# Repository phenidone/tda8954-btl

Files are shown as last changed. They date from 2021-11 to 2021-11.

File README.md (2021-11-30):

# TDA8954 Bridge Tied Load

This is a PCB design for a mono amplifier, using a TDA8954J in BTL configuration.

## Power

The board requires 41+41V DC.  Filtering caps are included, but a bridge 
rectifier is not as this is expected to be used with a switching supply.

The datasheet claims 420W into 8 ohms at 10% THD, or 330W at 0.5%, with a
41+41V supply.

The load impedance shall not be less than 8 ohms nominal.

## Unmute

The muting circuits are controlled via an opto-isolated input.  Provide 
5-24VDC on the UNMUTE port to enable the amplifiers.  This port allows the
amplifier to be put into a standby/mute mode, e.g. while preamplifiers are
booting.

## Components

Input capacitors (C7, C10) shall be film-type box capacitors, 5mm lead pitch.

The capacitor voltage ratings required are as follows:
 * Single-rail electrolytics (470uF) should be 63V
 * Dual-rail electrolytics (22uF) should be 160V
 * Single-rail MLCC (mostly 100n) should be 100V
 * Dual-rail MLCC supply caps should be 250V
 * Bootstrap and snubber MLCCs should be 250V
 * Output LC filter caps (C5, C11) are to be high-voltage (400V) film type

The output LC inductors should be low-loss cores with a saturation current
of not less than 10A.  Footprints are provided for
both Bourns SRP1265C (SMD shielded) and 2200HT-V (toroidal), though 
the toroids will overhang the edge of the PCB.  If toroidal inductors are used,
they should be affixed to the PCB with epoxy to prevent lead fatigue from 
vibration.

Power and output connectors are FASTON 1/4" spade terminals, though an extra
footprint for a 3-way screw terminal is provided for power input.

## EMI

The heatsink should be electrically connected to the HEATSINK spade terminal
connector at the corner of the board, and/or connected to safety-ground.

## License

This hardware design is (C) 2021 William Brodie-Tyrrell and is licensed under 
the CERN OHL; see cern_ohl_v_1_2.pdf

## TRL

This PCB has been sent for manufacture but not yet assembled or tested.

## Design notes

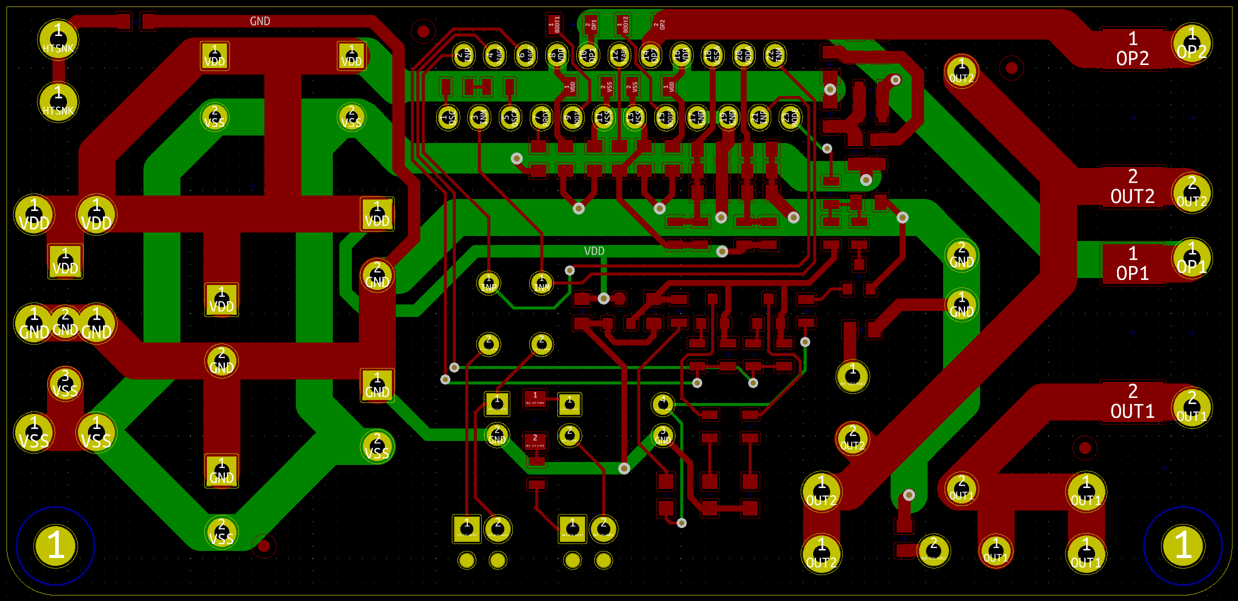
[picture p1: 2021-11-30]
tda8954-btl-layout.png

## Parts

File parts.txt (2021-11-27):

470u 63v electro, 4 of, multicomp MCRH63V477M13X26
22u 160v electro, 2 of, nichicon UVZ2C220MPD1TD
100n 250v 1206, 2 of, Wurth 885342208004
100n 100v 0805, 10 of, Multicomp MC0805B104K101CT
15n 250v 1206, 2 of, Kemet C1206C153KARECAUTO
220p 250v 0805, 4 of, Yageo CC0805KRX7RYBB221

1u film 5mm, 2 of, Wima MKS2C041001F00KSSD
22uH, 2 of, bourns SRP1265C-220M alt 2200HT-220-V-RC
680n film 15mm, 2 of, multicomp MPMPP400P68J0I200

terminal 2 way 3041529 15A
terminal 3 way 3041530 15A

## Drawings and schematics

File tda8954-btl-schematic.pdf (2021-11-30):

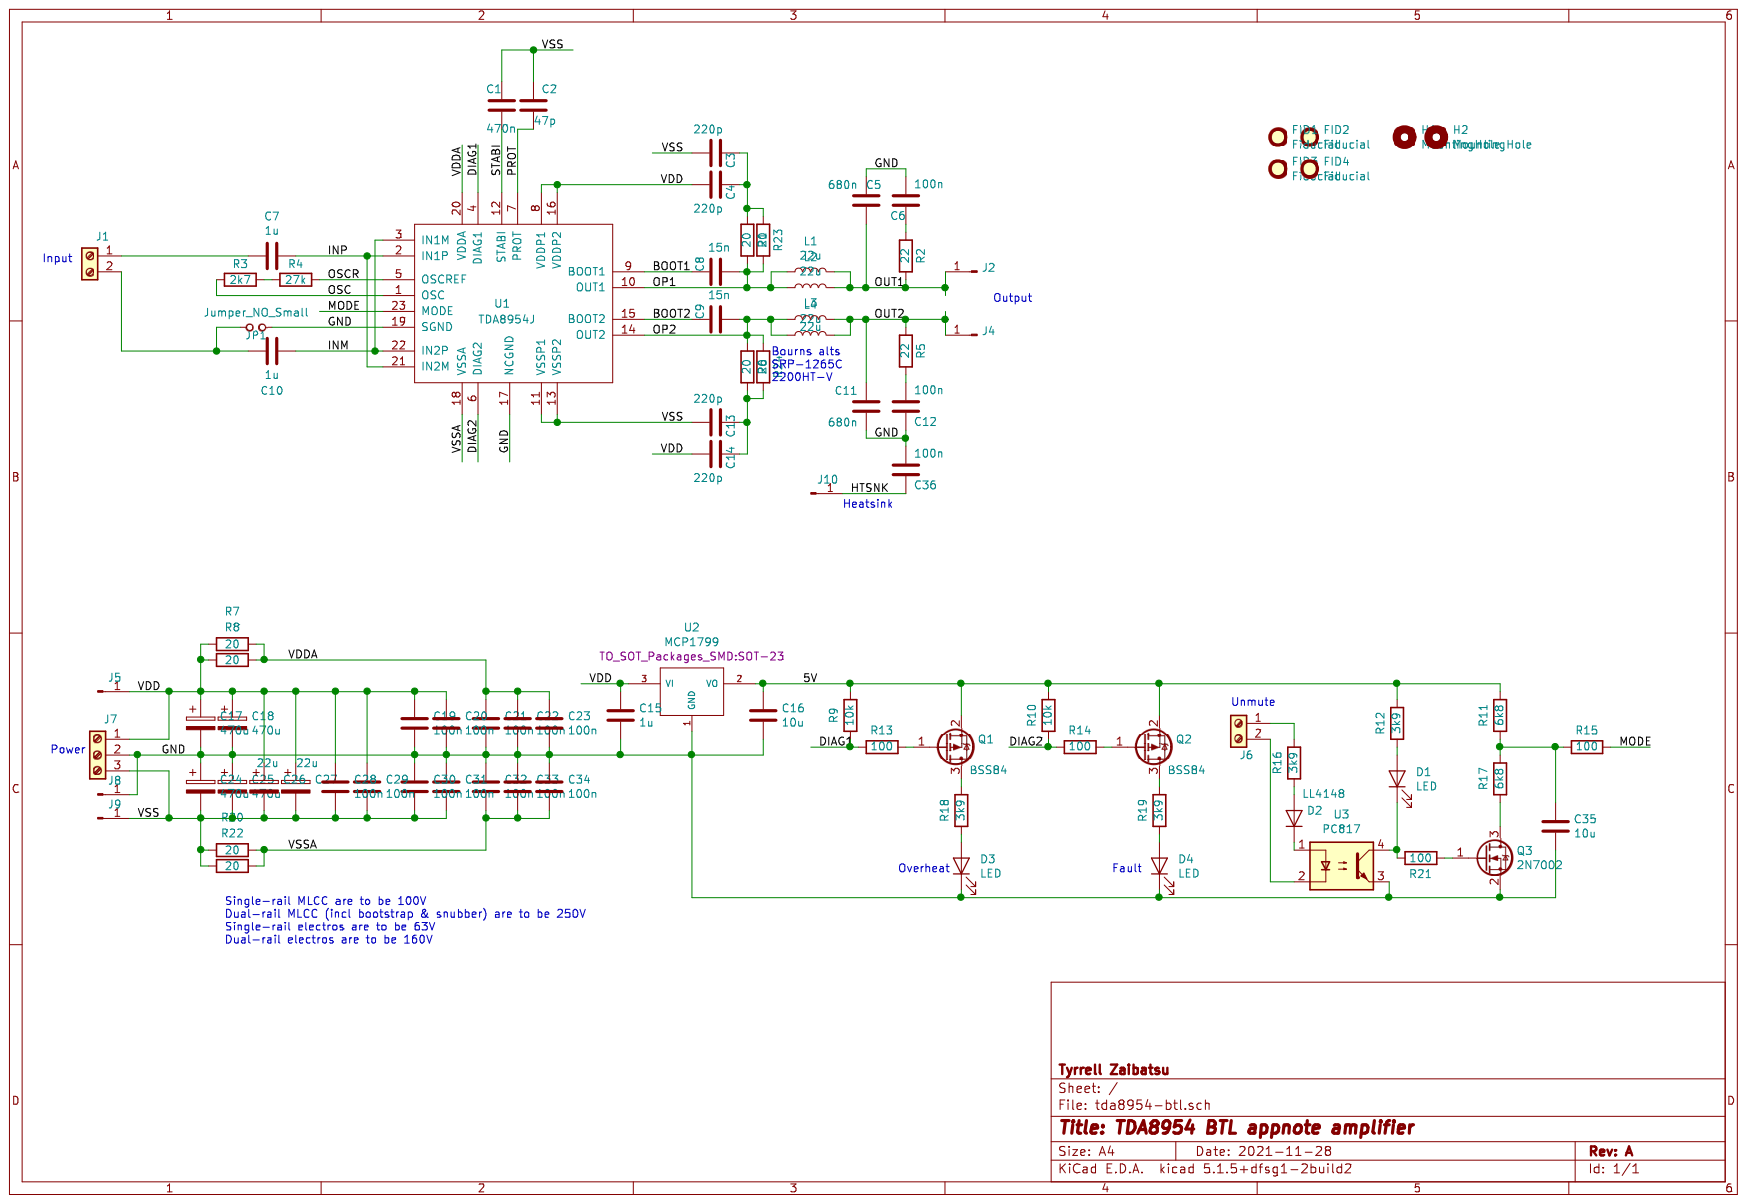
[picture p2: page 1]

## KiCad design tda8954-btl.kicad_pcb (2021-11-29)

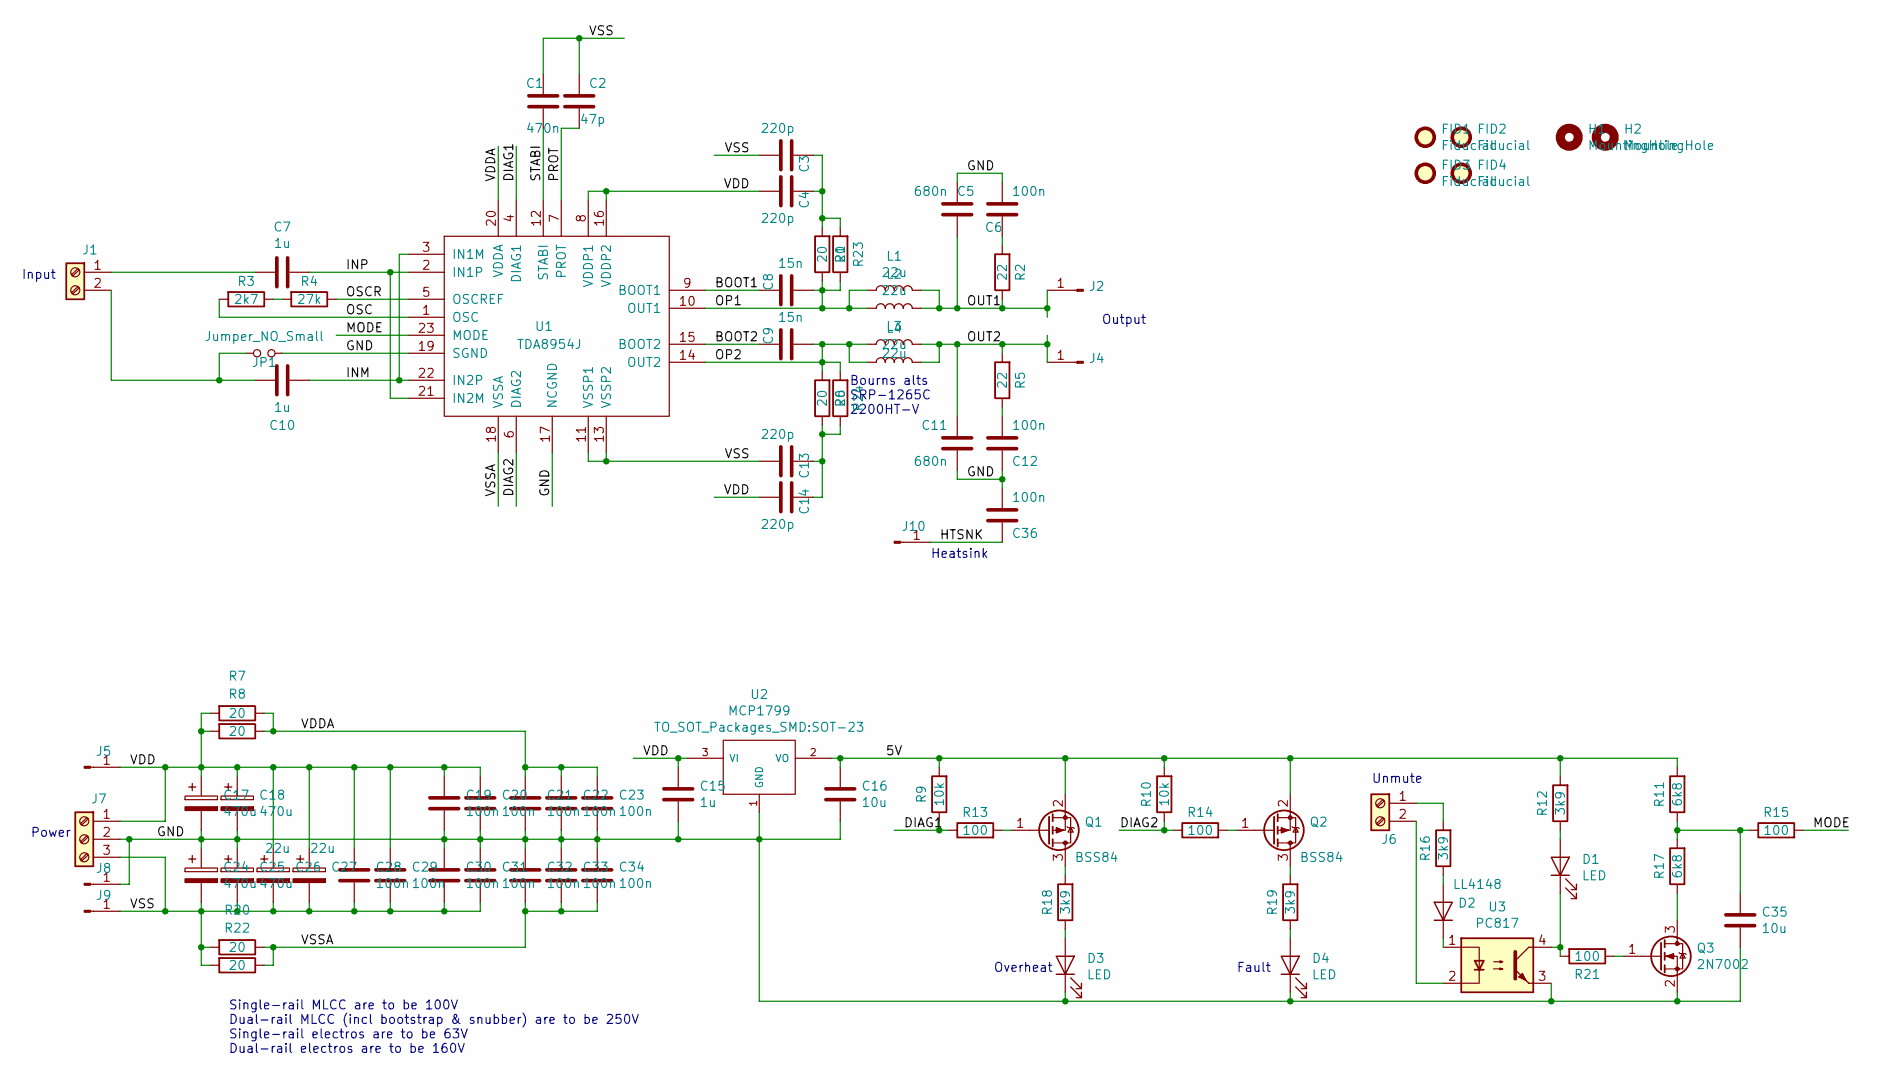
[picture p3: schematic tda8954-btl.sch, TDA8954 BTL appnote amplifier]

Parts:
C1: 470n; C_0805
C2: 47p; C_0805
C3, C4, C13, C14: 220p; C_0805
C5, C11: 680n; C_Rect_L18.0mm_W11.0mm_P15.00mm_FKS3_FKP3; MFG Part Num MPMPP400P68J0I200
C6, C12, C19, C20, C21, C22, C23, C30, C31, C32, C33, C34, C36: 100n; C_0805
C7, C10: 1u; C_Rect_L7.2mm_W3.5mm_P5.00mm_FKS2_FKP2_MKS2_MKP2
C8, C9: 15n; C_1206
C15: 1u; C_0805
C16, C35: 10u; C_0805
C17, C18, C24, C25: 470u; CP_Radial_D13.0mm_P5.00mm
C26, C27: 22u; CP_Radial_D10.0mm_P5.00mm
C28, C29: 100n; C_1206
D1, D3, D4: LED; LED_0805
D2: LL4148; D_MiniMELF
FID1, FID2, FID3, FID4: Fiducial; Fiducial_1mm_Dia_2mm_Outer
H1, H2: MountingHole; MountingHole_3.2mm_M3
J1, J6: Screw_Terminal_01x02; TerminalBlock_Phoenix_MPT-2.54mm_2pol
J2, J4, J5, J8, J9, J10: Conn_01x01_Male; FASTON250P_5.08mm_male_vertical
J7: Screw_Terminal_01x03; TerminalBlock_Phoenix_MKDS1.5-3pol
JP1: Jumper_NO_Small; Pin_Header_Straight_1x02_Pitch2.54mm
L1, L4: 22u; Bourns-2200HT-V; MFG Part Num SRP1265C-220M
L2, L3: 22u; SRP1265; MFG Part Num SRP1265C-220M
Q1, Q2: BSS84; SOT-23
Q3: 2N7002; SOT-23
R1, R6, R7, R8, R20, R22, R23, R24: 20; R_0805
R2, R5: 22; R_Axial_DIN0516_L15.5mm_D5.0mm_P5.08mm_Vertical
R3: 2k7; R_0805
R4: 27k; R_0805
R9, R10: 10k; R_0805
R11, R17: 6k8; R_0805
R12, R16, R18, R19: 3k9; R_0805
R13, R14, R15, R21: 100; R_0805
U1: TDA8954J; DBS23P
U2: MCP1799; SOT-23
U3: PC817; DIP-4_W7.62mm_Socket

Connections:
/5V: C16.1, Q1.2 (S), Q2.2 (S), R9.2, R10.2, R11.2, R12.2, U2.2 (VO)
/BOOT1: C8.1, U1.9 (BOOT1)
/BOOT2: C9.1, U1.15 (BOOT2)
/DIAG1: R9.1, R13.1, U1.4 (DIAG1)
/DIAG2: R10.1, R14.1, U1.6 (DIAG2)
/GND: C5.1, C6.2, C11.2, C12.1, C15.2, C16.2, C17.2, C18.2, C19.2, C20.2, C21.2, C22.2, C23.2, C24.1, C25.1, C30.1, C31.1, C32.1, C33.1, C34.1, C35.2, C36.2, D3.1 (K), D4.1 (K), J7.2, J8.1, JP1.2, Q3.2 (S), U1.17 (NCGND), U1.19 (SGND), U2.1 (GND), U3.3
/HTSNK: C36.1, J10.1
/INM: C10.1, U1.3 (IN1M), U1.22 (IN2P)
/INP: C7.1, U1.2 (IN1P), U1.21 (IN2M)
/MODE: R15.2, U1.23 (MODE)
/OP1: C8.2, L1.1, L2.1, R1.1, R23.1, U1.10 (OUT1)
/OP2: C9.2, L3.1, L4.1, R6.2, R24.2, U1.14 (OUT2)
/OSC: R3.2, U1.1 (OSC)
/OSCR: R4.1, U1.5 (OSCREF)
/OUT1: C5.2, J2.1, L1.2, L2.2, R2.1
/OUT2: C11.1, J4.1, L3.2, L4.2, R5.2
/PROT: C2.1, U1.7 (PROT)
/STABI: C1.1, U1.12 (STABI)
/VDD: C4.2, C14.2, C15.1, C17.1, C18.1, C19.1, C20.1, C26.1, C27.1, C28.1, C29.1, J5.1, J7.1, R7.2, R8.2, U1.8 (VDDP1), U1.16 (VDDP2), U2.3 (VI)
/VDDA: C21.1, C22.1, C23.1, R7.1, R8.1, U1.20 (VDDA)
/VSS: C1.2, C2.2, C3.2, C13.2, C24.2, C25.2, C26.2, C27.2, C28.2, C29.2, C30.2, C31.2, J7.3, J9.1, R20.2, R22.2, U1.11 (VSSP1), U1.13 (VSSP2)
/VSSA: C32.2, C33.2, C34.2, R20.1, R22.1, U1.18 (VSSA)
unnamed: C3.1, C4.1, R1.2, R23.2
unnamed: C6.1, R2.2
unnamed: C7.2, J1.1
unnamed: C10.2, J1.2, JP1.1
unnamed: C12.2, R5.1
unnamed: C13.1, C14.1, R6.1, R24.1
unnamed: C35.1, R11.1, R15.1, R17.2
unnamed: D1.1 (K), R21.2, U3.4
unnamed: D1.2 (A), R12.1
unnamed: D2.1 (K), U3.1
unnamed: D2.2 (A), R16.1
unnamed: D3.2 (A), R18.1
unnamed: D4.2 (A), R19.1
unnamed: J6.1, R16.2
unnamed: J6.2, U3.2
unnamed: Q1.1 (G), R13.2
unnamed: Q1.3 (D), R18.2
unnamed: Q2.1 (G), R14.2
unnamed: Q2.3 (D), R19.2
unnamed: Q3.1 (G), R21.1
unnamed: Q3.3 (D), R17.1
unnamed: R3.1, R4.2

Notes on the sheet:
Power
Single-rail MLCC are to be 100V Dual-rail MLCC (incl bootstrap & snubber) are to be 250V Single-rail electros are to be 63V Dual-rail electros are to be 160V
Input
Output
Bourns alts SRP-1265C 2200HT-V
Unmute
Overheat
Fault
Heatsink

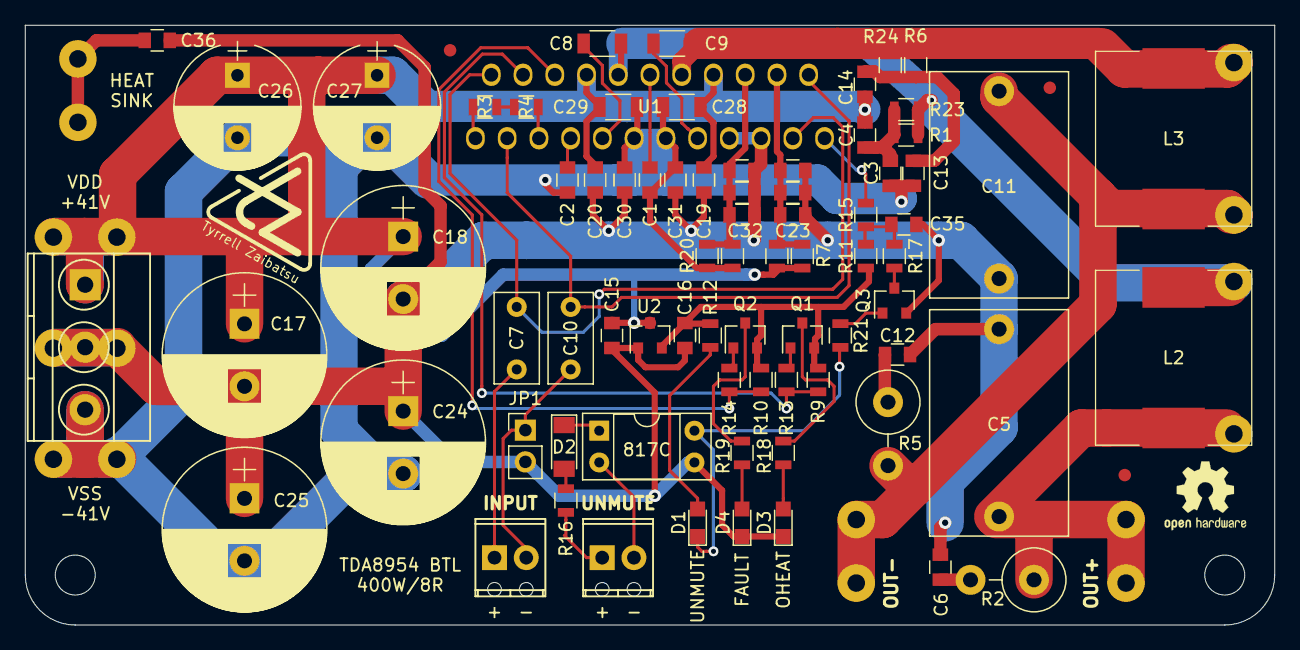
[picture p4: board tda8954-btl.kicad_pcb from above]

Board: 2 copper layers, 100.0 x 48.0 mm, 90 parts (0 on the bottom side), 44 nets.

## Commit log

2021-11-27 First draft schematic and layout
    [tda8954-btl.kicad_pcb, tda8954-btl.sch]
2021-11-27 polishing; completed first pass layout
    [tda8954-btl.kicad_pcb, tda8954-btl.sch]
2021-11-28 polishing, plotted gerbers
    [tda8954-btl-B_Cu.gbr, tda8954-btl-B_Mask.gbr, tda8954-btl-B_Paste.gbr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]
2021-11-29 fixed footprints, re-plotted
    [tda8954-btl-B_Cu.gbr, tda8954-btl-B_Mask.gbr, tda8954-btl-B_Paste.gbr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]
2021-11-30 added schematic PDF and layout PNG
